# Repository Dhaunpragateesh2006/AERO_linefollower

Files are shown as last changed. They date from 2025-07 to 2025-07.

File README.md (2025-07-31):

# AERO_linefollower

**AERO** is an autonomous line follower bot designed to detect and follow a path using IR sensors and motor control logic. It features an open-source hardware design with schematics and PCB layout, making it ideal for learning robotics, embedded systems, and circuit design.

## 🚀 Features

- Follows black or white lines using IR sensor array
- PWM motor control via TB6612 driver
- Custom PCB design 
- Fully open-source hardware and firmware
- Modular and compact design

---

## 🧠 Tech Stack

- **Microcontroller:** Arduino  Nano / 
- **Programming:** Arduino IDE (C++)
- **PCB Design:** KiCad 

---

## 🔩 Hardware Components

| Component | Quantity | Description |
|---|---|---|
| Arduino Nano/ | 1 | Microcontroller board |
| QTR8RC | 1 | 8 channel IR array |
| TB6612FNG Motor Driver | 1 | Dual H-bridge for DC motors |
| N20 Motors + Wheels | 2 | Robot locomotion |
| 12V Li-Po | 1 | Li-polymer battery |
| Custom PCB | 1 | Hand Soldered |
| Chassis | 1 | 3-D printed |

---
## 🖼️ Schematic & PCB Design

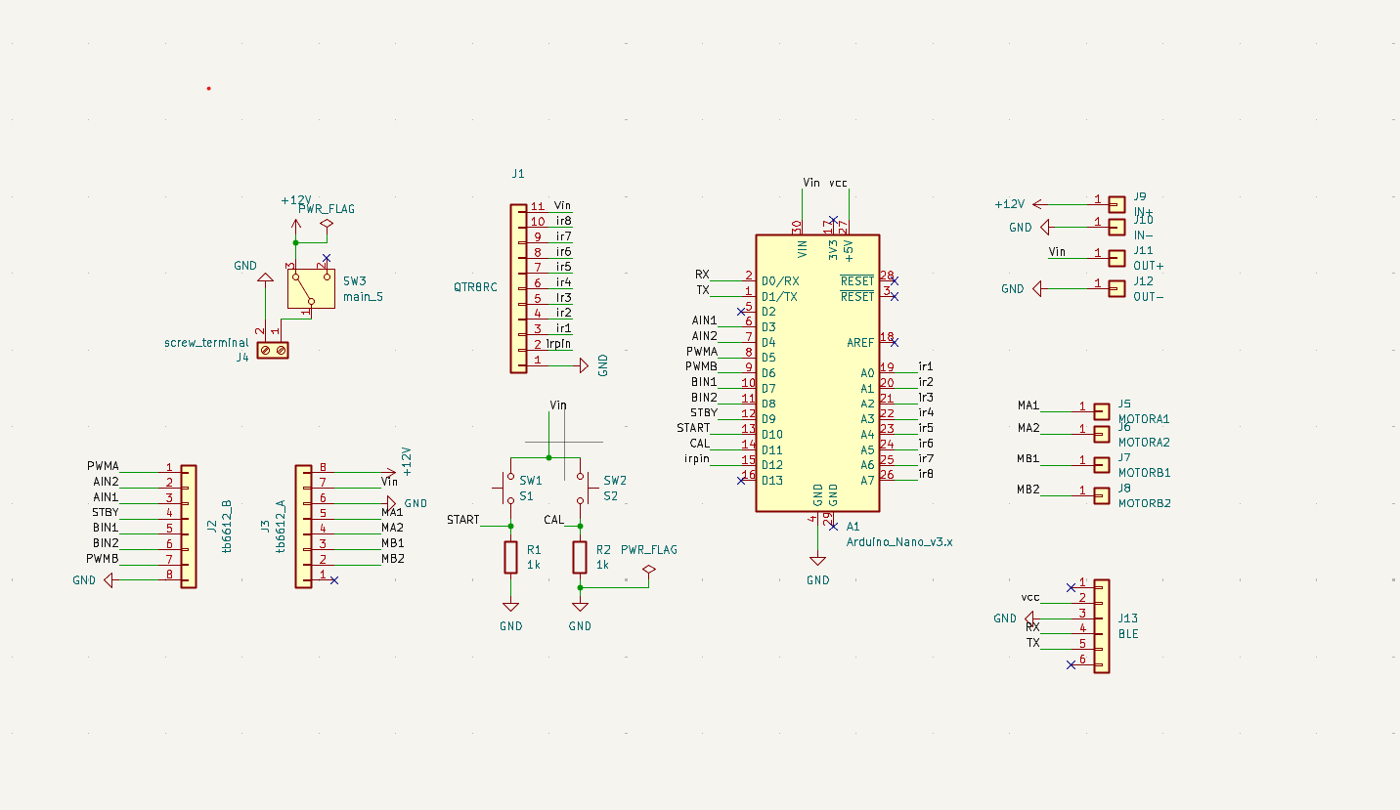
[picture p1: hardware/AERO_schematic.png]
Schematic


### 🧾 PCB Layout

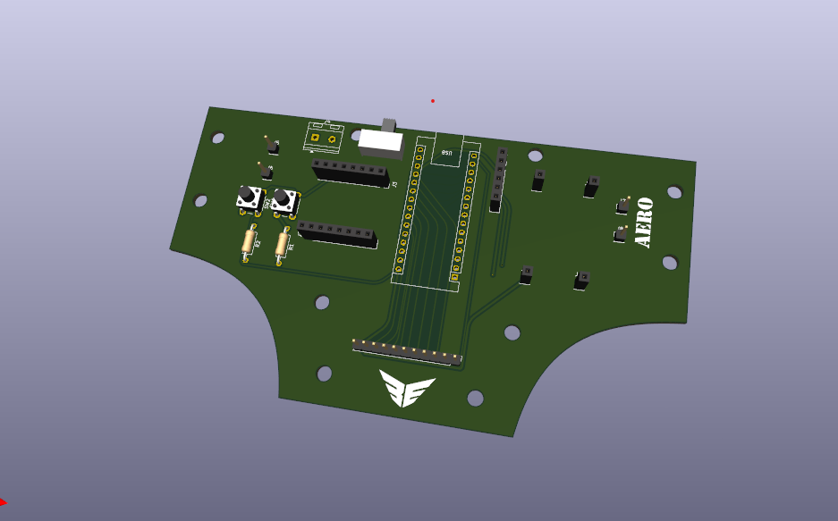
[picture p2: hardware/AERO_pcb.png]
PCB Layout


### 🤖 3-D Model

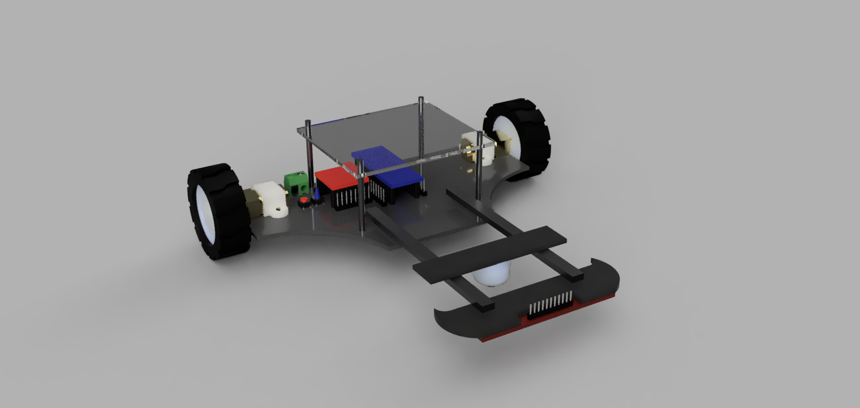
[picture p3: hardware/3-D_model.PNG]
3-D Model


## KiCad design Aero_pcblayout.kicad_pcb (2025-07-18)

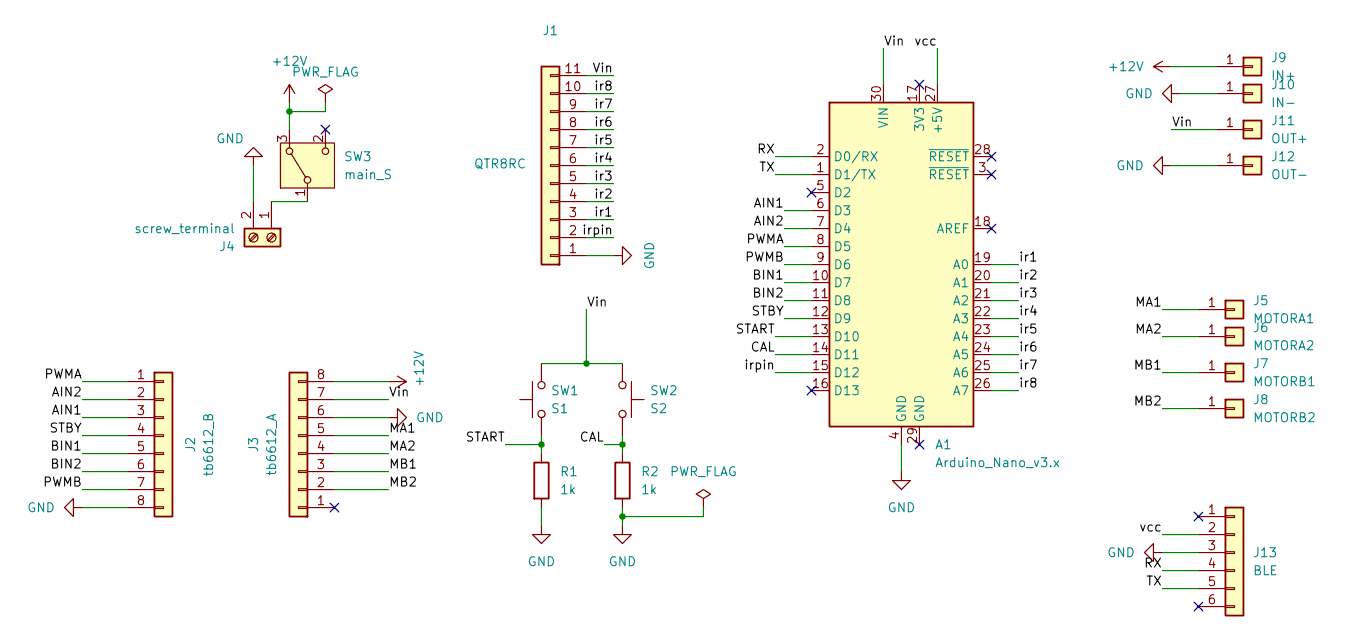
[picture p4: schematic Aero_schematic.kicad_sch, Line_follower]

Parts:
A1: Arduino_Nano_v3.x; Arduino_Nano
J1: QTR8RC; PinHeader_1x11_P2.54mm_Vertical
J2: tb6612_B; PinSocket_1x08_P2.54mm_Vertical
J3: tb6612_A; PinSocket_1x08_P2.54mm_Vertical
J4: screw_terminal; TerminalBlock_RND_205-00232_1x02_P5.08mm_Horizontal
J5: MOTORA1; PinHeader_1x01_P2.54mm_Vertical
J6: MOTORA2; PinHeader_1x01_P2.54mm_Vertical
J7: MOTORB1; PinHeader_1x01_P2.54mm_Vertical
J8: MOTORB2; PinHeader_1x01_P2.54mm_Vertical
J9: IN+; PinSocket_1x01_P2.54mm_Vertical
J10: IN-; PinSocket_1x01_P2.54mm_Vertical
J11: OUT+; PinSocket_1x01_P2.54mm_Vertical
J12: OUT-; PinSocket_1x01_P2.54mm_Vertical
J13: BLE; PinSocket_1x06_P2.54mm_Vertical
R1, R2: 1k; R_Axial_DIN0207_L6.3mm_D2.5mm_P10.16mm_Horizontal
SW1: S1; SW_PUSH_6mm_H7.3mm
SW2: S2; SW_PUSH_6mm_H7.3mm
SW3: main_S; SW_Slide-03_Wuerth-WS-SLTV_10x2.5x6.4_P2.54mm

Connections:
+12V: J3.8, J9.1, SW3.3 (A)
/AIN1: A1.6 (D3), J2.3
/AIN2: A1.7 (D4), J2.2
/BIN1: A1.10 (D7), J2.5
/BIN2: A1.11 (D8), J2.6
/CAL: A1.14 (D11), R2.1, SW2.2
/MA1: J3.5, J5.1
/MA2: J3.4, J6.1
/MB1: J3.3, J7.1
/MB2: J3.2, J8.1
/PWMA: A1.8 (D5), J2.1
/PWMB: A1.9 (D6), J2.7
/RX: A1.2 (D0/RX), J13.4
/START: A1.13 (D10), R1.1, SW1.1
/STBY: A1.12 (D9), J2.4
/TX: A1.1 (D1/TX), J13.5
/Vin: A1.30 (VIN), J1.11, J3.7, J11.1, SW1.2, SW2.1
/ir1: A1.19 (A0), J1.3
/ir2: A1.20 (A1), J1.4
/ir3: A1.21 (A2), J1.5
/ir4: A1.22 (A3), J1.6
/ir5: A1.23 (A4), J1.7
/ir6: A1.24 (A5), J1.8
/ir7: A1.25 (A6), J1.9
/ir8: A1.26 (A7), J1.10
/irpin: A1.15 (D12), J1.2
/vcc: A1.27 (+5V), J13.2
GND: A1.4 (GND), J1.1, J2.8, J3.6, J4.2, J10.1, J12.1, J13.3, R1.2, R2.2
unnamed: J4.1, SW3.1 (B)

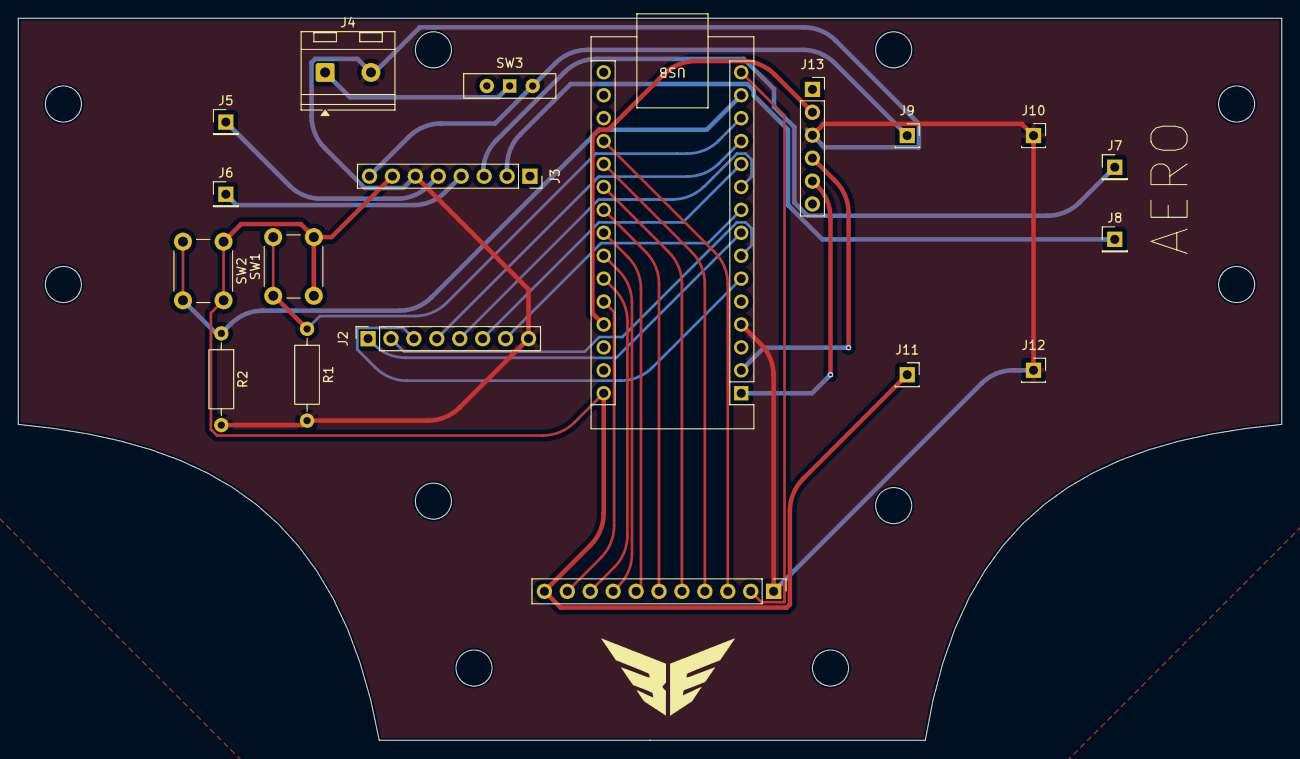
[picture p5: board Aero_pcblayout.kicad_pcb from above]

Board: 2 copper layers, 140.0 x 80.0 mm, 19 parts (0 on the bottom side), 29 nets.

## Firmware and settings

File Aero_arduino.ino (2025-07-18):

#include <QTRSensors.h>
#include <SparkFun_TB6612.h>
#include <SoftwareSerial.h>

SoftwareSerial HC05(2, 13); // RX, TX
char data;

// QTR Sensor
QTRSensors qtr;
const uint8_t SensorCount = 8;
uint16_t sensorValues[SensorCount];

// PID
float Kp = 0.09;
float Ki = 0.0001;
float Kd = 0.33;
int P, I, D, lastError = 0;

// Motor settings
int TURN_SPEED = 200;
const int BLACK_THRESHOLD = 700;
bool turning = false;
String turnDirection = "";

// Speed parameters
uint8_t maxspeeda = 225;
uint8_t maxspeedb = 225;
uint8_t basespeeda = 175;
uint8_t basespeedb = 175;

#define AIN1 3
#define BIN1 7
#define AIN2 4
#define BIN2 8
#define PWMA 5
#define PWMB 6
#define STBY 9

int buttoncalibrate = 10;
int buttonstart = 11;

const int offsetA = 1;
const int offsetB = 1;
Motor motor1 = Motor(AIN1, AIN2, PWMA, offsetA, STBY);
Motor motor2 = Motor(BIN1, BIN2, PWMB, offsetB, STBY);

// Ramp control
uint8_t currentSpeedA = 0;
uint8_t currentSpeedB = 0;
const uint8_t rampStep = 5;
const uint16_t rampDelay = 15;
unsigned long lastRampTime = 0;

boolean onoff = false;

void setup() {
  qtr.setTypeAnalog();
  qtr.setSensorPins((const uint8_t[]){A0, A1, A2, A3, A4, A5, A6, A7}, SensorCount);
  qtr.setEmitterPin(12);

  HC05.begin(9600);
  Serial.begin(9600);
  
  delay(500);
  pinMode(LED_BUILTIN, OUTPUT);
  pinMode(buttoncalibrate, INPUT);
  pinMode(buttonstart, INPUT);

  boolean Ok = false;
  while (!Ok) {
    if (digitalRead(buttoncalibrate) == HIGH) {
      delay(2000);
      calibration();
      Ok = true;
    }
  }
  brake(motor1, motor2);
}

void calibration() {
  digitalWrite(LED_BUILTIN, HIGH);
  for (uint16_t i = 0; i < 50; i++) {
    motor1.drive(25);
    motor2.drive(-25);
    qtr.calibrate();
    delay(20);
  }
  for (uint16_t i = 0; i < 50; i++) {
    motor1.drive(-25);
    motor2.drive(25);
    qtr.calibrate();
    delay(20);
  }
  brake(motor1, motor2);
  digitalWrite(LED_BUILTIN, LOW);
}

void loop() {
  // Bluetooth input
  if (HC05.available()) {
    data = HC05.read();
    if (data == 'i') Kp += 0.005;
    else if (data == 'd') Kp -= 0.005;
    else if (data == 'j') Ki += 0.00005;
    else if (data == 'e') Ki -= 0.00005;
    else if (data == 'k') Kd += 0.01;
    else if (data == 'f') Kd -= 0.01;
    else if (data == 'l') {
      maxspeeda += 25; maxspeedb += 25;
      basespeeda += 25; basespeedb += 25;
    }
    else if (data == 'g') {
      maxspeeda -= 25; maxspeedb -= 25;
      basespeeda -= 25; basespeedb -= 25;
    }
    else if (data == 's') {
      onoff = false;
      P = I = D = 0;
    }
    else if (data == 'S') {
      onoff = true;
      currentSpeedA = 0;
      currentSpeedB = 0;
      lastRampTime = millis();
    }
    else if (data == 't') TURN_SPEED += 10;
    else if (data == 'T') TURN_SPEED -= 10;

    HC05.print(Kp); HC05.print(" ");
    HC05.print(Ki); HC05.print(" ");
    HC05.println(Kd);
    HC05.print(basespeeda); HC05.print(" ");
    HC05.print(maxspeeda);
  }

  // Button toggle
  if (digitalRead(buttonstart) == HIGH) {
    onoff = !onoff;
    delay(500);
    if (onoff) {
      currentSpeedA = 0;
      currentSpeedB = 0;
      lastRampTime = millis();
    }
  }

  if (onoff) {
    // Gradually increase speed
    if (millis() - lastRampTime >= rampDelay) {
      lastRampTime = millis();
      if (currentSpeedA < basespeeda) currentSpeedA += rampStep;
      if (currentSpeedB < basespeedb) currentSpeedB += rampStep;
    }
    PID_control(currentSpeedA, currentSpeedB);
  } else {
    brake(motor1, motor2);
  }
}

void forward_brake(int posa, int posb) {
  motor1.drive(posa);
  motor2.drive(posb);
}

void PID_control(uint8_t baseA, uint8_t baseB) {
  uint16_t position = qtr.readLineBlack(sensorValues);
  int error = 3500 - position;

  P = error;
  I += error;
  D = error - lastError;
  lastError = error;

  int motorspeed = P * Kp + I * Ki + D * Kd;
  int motorspeeda = baseA + motorspeed;
  int motorspeedb = baseB - motorspeed;

  motorspeeda = constrain(motorspeeda, 0, maxspeeda);
  motorspeedb = constrain(motorspeedb, 0, maxspeedb);

  qtr.read(sensorValues);

  bool lineCentered = (sensorValues[3] > BLACK_THRESHOLD || sensorValues[4] > BLACK_THRESHOLD);
  bool leftTurn = (sensorValues[0] > BLACK_THRESHOLD || sensorValues[1] > BLACK_THRESHOLD);
  bool rightTurn = (sensorValues[6] > BLACK_THRESHOLD || sensorValues[7] > BLACK_THRESHOLD);

  if (turning) {
    if (lineCentered) {
      turning = false;
      turnDirection = "";
    } else {
      if (turnDirection == "left") {
        motor1.drive(TURN_SPEED);
        motor2.drive(-(TURN_SPEED*0.30));
      } else if (turnDirection == "right") {
        motor1.drive(-(TURN_SPEED*0.30));
        motor2.drive(TURN_SPEED);
      }
      return;
    }
  }

  if (leftTurn && !rightTurn) {
    motor1.drive(-30);
    motor2.drive(-30);
    delay(50);
    turning = true;
    turnDirection = "left";
  } else if (rightTurn && !leftTurn) {
    motor1.drive(-30);
    motor2.drive(-30);
    delay(50);
    turning = true;
    turnDirection = "right";
  } else {
    forward_brake(motorspeeda, motorspeedb);
  }
}
